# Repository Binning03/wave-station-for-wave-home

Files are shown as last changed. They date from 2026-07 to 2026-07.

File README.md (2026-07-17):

# WaveStation

> ESP32 기반 멀티모달 스마트홈 엣지 게이트웨이  
> 마이크·스피커·IR·환경 센서를 하나의 장치에 통합하고, 자체 설계한 **WSP(WaveStation Protocol)** 로 WaveHome 백엔드와 실시간 데이터를 주고받습니다.

WaveStation은 단순히 여러 센서를 ESP32에 연결한 장치가 아닙니다. 실시간 오디오 수집과 압축, 양방향 장치 제어, TCP 스트림 파싱, 구독 기반 데이터 전송, 오류 응답, 연결 복구까지 직접 설계한 **펌웨어·통신 미들웨어·테스트 백엔드 통합 프로젝트**입니다.

WaveHome 전체 시스템에서는 실제 공간의 데이터를 수집하고 제어 명령을 실행하는 디바이스 계층을 담당합니다. 이를 통해 **디바이스 → 엣지 펌웨어 → 네트워크 프로토콜 → 백엔드 → AI 서비스**로 이어지는 End-to-End 사용자 케어 시스템의 핵심 연결 지점을 구현했습니다.

---

## 핵심 구현 내용

| 영역 | 구현 내용 |
|---|---|
| Embedded Firmware | ESP32 기반 펌웨어, Wi-Fi 연결, 장치 초기화 및 세션 관리 |
| Audio Input/Output | INMP441 I2S 마이크 입력, MAX98357 I2S 스피커 출력 |
| Real-time Audio | 16 kHz·mono·16-bit PCM을 20 ms 프레임으로 실시간 스트리밍 |
| Audio Compression | ESP32 내부 Opus 인코딩·디코딩, 16 kbps 음성 스트림 전송 |
| Infrared | 리모컨 raw timing 수신 및 38 kHz 기반 IR 재송신 |
| Environment Sensors | DHT22 온도·습도, BH1750 조도 센서 연동 |
| Network | ESP32 TCP 서버, 부분 송신 재시도, TCP 스트림 누적 파싱 |
| WSP Protocol | 16-byte 바이너리 헤더, 데이터 타입, sequence, requestId 설계 |
| Control Messages | Subscribe, Unsubscribe, Heartbeat, Ack, Error 처리 |
| Error Handling | 미지원 기능, 잘못된 payload, 장치 준비 실패, 재생 실패 응답 |
| Execution Structure | 확장된 Arduino `loopTask` 안에서 기능별 비차단 폴링 루틴과 드라이버 모듈 분리 |
| Reliability | 스택 오버플로, 연결 종료·재연결, I2S 채널 문제, 라이브러리 충돌 디버깅 |
| Test Backend | 펌웨어와 함께 Python WSP 테스트 클라이언트 및 오디오 분석 도구 개발 |
| Enclosure | 센서 배치와 설치 환경을 고려한 OpenSCAD 케이스 및 STL 제작 |

### 이 프로젝트에서 특히 강조한 부분

- 단순 센서 연결보다 **직접 설계한 소프트웨어 구조와 문제 해결 과정**에 집중했습니다.
- 실시간 오디오가 프레임 단위로 끊기지 않도록 I2S 수집, 압축, TCP 송신 흐름을 연결했습니다.
- 제한된 ESP32 메모리와 스택을 고려해 큰 버퍼는 정적으로 관리하고 `loopTask` 스택을 **49,152 bytes**로 확장했습니다.
- TCP 위에서 사용할 바이너리 패킷의 헤더, 명령, 응답, 순서 번호 구조를 직접 정의했습니다.
- 장치가 지원하지 않거나 준비되지 않은 명령에는 `ErrorUnsupported` 등의 오류를 반환합니다.
- 연결이 종료되면 세션 상태와 sequence를 초기화하고 다음 백엔드 연결을 받을 수 있도록 구성했습니다.
- 실제 펌웨어와 동일한 프로토콜을 사용하는 Python 테스트 백엔드를 함께 만들어 기능을 독립적으로 검증했습니다.

---

## WaveHome에서의 역할

WaveHome은 수면 상태, 자세, 실내 환경 등을 종합적으로 관리하는 사용자 케어 스마트홈 시스템입니다. WaveStation은 그중 물리 환경과 서버를 연결하는 엣지 게이트웨이입니다.

```mermaid
flowchart LR
    subgraph Device["WaveStation Device"]
        MIC[INMP441 Microphone]
        IRRX[IR Receiver]
        IRTX[IR Transmitter]
        DHT[DHT22]
        LIGHT[BH1750]
        SPK[MAX98357 + Speaker]
        ESP[ESP32 Firmware]

        MIC --> ESP
        IRRX --> ESP
        DHT --> ESP
        LIGHT --> ESP
        ESP --> IRTX
        ESP --> SPK
    end

    ESP <-->|"TCP :41737 / WSP"| BACKEND[WaveHome Backend]
    BACKEND --> AI[Care Logic / AI Services]
    AI --> BACKEND
```

### 수집 방향

- 마이크 → PCM 또는 Opus → WaveHome 백엔드
- IR 수신기 → raw timing → WaveHome 백엔드
- BH1750 → 조도(lux) → WaveHome 백엔드
- DHT22 → 온도(°C)·습도(%) → WaveHome 백엔드

### 제어 방향

- WaveHome 백엔드 → IR raw timing → 기존 에어컨·가전 제어
- WaveHome 백엔드 → PCM 또는 Opus → 스피커 안내·알림 출력

이 저장소는 AI 분석 모델 자체보다 **디바이스 및 게이트웨이 계층**에 집중합니다. WaveHome 백엔드·AI 서비스와 결합하면 센서 입력부터 사용자 케어 동작까지 이어지는 End-to-End 시스템을 구성할 수 있습니다.

---

## 시스템 구성

```text
Sensors / Audio / IR
        ↓
ESP32 Hardware Drivers
        ↓
Feature Polling Routines
        ↓
WSP Packet Builder / Parser
        ↓
TCP Server :41737
        ↕
Python Test Backend or WaveHome Backend
```

### TCP 역할

| 구성 요소 | 역할 |
|---|---|
| ESP32 | TCP 서버, `41737` 포트에서 연결 대기 |
| Python/WaveHome 백엔드 | TCP 클라이언트, ESP32 LAN IP로 연결 |

ESP32는 한 번에 하나의 백엔드 연결을 처리합니다. 연결된 클라이언트에는 `TCP_NODELAY`를 적용해 작은 오디오 프레임의 지연을 줄입니다.

---

## 펌웨어 실행 구조

### 실제 실행 모델

ESP32 Arduino Core는 `setup()`과 `loop()`를 실행하는 FreeRTOS `loopTask`를 생성합니다. WaveStation은 Opus 인코더·디코더와 오디오 처리 과정에서 발생한 스택 오버플로를 해결하기 위해 해당 Task의 스택 크기를 **49,152 bytes**로 확장했습니다.

`appLoop()`에서는 다음 루틴을 짧게 반복합니다.

| 실행 루틴 | 책임 |
|---|---|
| TCP 수신 루틴 | 스트림 데이터 누적, WSP 패킷 경계 복원, 명령 dispatch |
| IR 수신 루틴 | 구독 상태일 때 리모컨 raw timing 확인 및 전송 |
| 센서 루틴 | 구독 주기와 변화량 조건을 확인해 환경 데이터 전송 |
| 마이크 루틴 | 20 ms PCM 프레임 수집, PCM/Opus 패킷 송신 |

기능별 로직은 다음 모듈로 분리되어 있습니다.

| 모듈 | 역할 |
|---|---|
| `app.cpp` | Wi-Fi, TCP 세션, 구독 상태, WSP 수신 dispatch, 기능 폴링 |
| `wave_station.h` | WSP 상수, 타입, 헤더와 payload 구조 정의 |
| `wsp_packet.*` | Ack/Error/Heartbeat 및 데이터 패킷 생성·송신 |
| `i2s_mic.*` | INMP441 I2S 입력과 PCM 변환 |
| `opus_codec.*` | MicComp 인코딩과 SpkComp 디코딩 |
| `ir_driver.*` | IR raw timing 수신·송신 |
| `sensor_driver.*` | DHT22·BH1750 초기화와 측정 |
| `speaker_driver.*` | MAX98357 I2S 출력 |

이 구조는 기능 책임을 분리하면서도, 별도 Task 간 Queue와 동기화 비용을 추가하지 않고 현재 규모의 기능을 하나의 실행 흐름에서 관리하도록 설계한 것입니다.

---

## WSP: WaveStation Protocol

WSP는 WaveStation과 백엔드가 오디오, IR, 센서, 제어 메시지를 동일한 형식으로 교환하기 위해 설계한 바이너리 프로토콜입니다.

### 기본 규격

| 항목 | 값 |
|---|---:|
| Protocol identifier | `0x57535031` |
| Version | `1` |
| Byte order | Little-endian |
| Header size | `16 bytes` |
| Maximum payload | `4,096 bytes` |
| TCP receive buffer | `8,192 bytes` |
| TCP port | `41737` |

모든 메시지는 고정 헤더와 가변 payload로 구성됩니다.

```text
16-byte Header | payloadSize bytes
```

### 헤더 분리

| 헤더 | 마지막 4-byte 필드 | 용도 |
|---|---|---|
| ControlHeader | `requestId` | Subscribe, Unsubscribe, Ack, Error, Heartbeat |
| DataHeader | `sequence` | PCM, Opus, IR, 센서 데이터 |

- `requestId`는 요청과 Ack/Error 응답을 연결합니다.
- `sequence`는 타입별 데이터 순서와 누락을 확인하는 데 사용합니다.
- 두 헤더는 모두 16 bytes이며 공통 앞부분을 사용합니다.

### 지원 메시지 타입

| Type | 값 | 방향 | 용도 |
|---|---:|---|---|
| MicPCM | `0x0101` | Device → Host | 원본 PCM 마이크 스트림 |
| MicComp | `0x0102` | Device → Host | Opus 압축 마이크 스트림 |
| SpkPCM | `0x0111` | Host → Device | PCM 스피커 재생 |
| SpkComp | `0x0112` | Host → Device | Opus 스피커 재생 |
| IrReceive | `0x0201` | Device → Host | IR raw timing 수신 결과 |
| IrTransmit | `0x0202` | Host → Device | IR raw timing 송신 명령 |
| AmbientLight | `0x0301` | Device → Host | 조도 |
| Temperature | `0x0302` | Device → Host | 온도 |
| Humidity | `0x0303` | Device → Host | 습도 |
| Subscribe | `0xF001` | Host → Device | 데이터 전송 시작 |
| Unsubscribe | `0xF002` | Host → Device | 데이터 전송 중지 |
| Ack | `0xF010` | Both | 요청 성공 응답 |
| Error | `0xF011` | Both | 요청 실패 응답 |
| Heartbeat | `0xF020` | Both | 연결 생존 확인 |

### Subscribe / Unsubscribe

백엔드는 필요한 데이터만 구독할 수 있습니다.

```mermaid
sequenceDiagram
    participant H as Backend
    participant D as WaveStation

    H->>D: Subscribe(Temperature, intervalMs)
    D->>H: Ack(requestId, status=0)
    loop Subscription enabled
        D->>H: Temperature(sequence, value)
    end
    H->>D: Unsubscribe(Temperature)
    D->>H: Ack(requestId, status=0)
```

구독 가능한 타입은 다음과 같습니다.

- MicPCM
- MicComp
- IrReceive
- AmbientLight
- Temperature
- Humidity

`SpkPCM`, `SpkComp`, `IrTransmit`은 구독 스트림이 아니라 백엔드가 필요할 때 보내는 일회성 Data 패킷입니다.

### Heartbeat

백엔드가 Heartbeat를 보내면 ESP32는 동일한 `requestId`로 Heartbeat를 반환합니다. Python 테스트 백엔드의 기본 주기는 **5초**이며 `0`으로 설정하면 비활성화할 수 있습니다.

### Ack와 Error

지원되는 Subscribe/Unsubscribe 요청이 정상 처리되면 `Ack(status=0)`를 반환합니다. 다음 상황에서는 Error 패킷을 반환합니다.

| 오류 코드 | 값 | 예시 |
|---|---:|---|
| ErrorUnsupported | `-1` | 미지원 타입, Opus/스피커/센서 준비 실패, 지원하지 않는 오디오 형식 |
| ErrorBusy | `-2` | 스피커 재생 실패 |
| ErrorInvalidPayload | `-3` | 잘못된 길이, 크기, sample count, IR raw 구조 |

오류 메시지는 최대 **96 bytes**까지 함께 전송합니다.

### TCP 스트림 파싱

TCP의 한 번의 `read()`는 WSP 패킷 하나와 일치하지 않을 수 있습니다. WaveStation은 수신 데이터를 **8 KB 버퍼**에 누적한 뒤 다음 조건을 확인합니다.

1. 16-byte 헤더가 모두 수신되었는지 확인
2. protocol identifier와 version 검증
3. payload가 4,096 bytes 이하인지 검증
4. 헤더와 payload 전체가 모일 때까지 대기
5. 완성된 패킷만 dispatch
6. 남은 바이트를 버퍼 앞으로 이동

잘못된 identifier/version, 과도한 payload, 수신 버퍼 overflow가 발생하면 연결을 종료해 파서 상태가 오염되는 것을 방지합니다.

### 송신 안정성

`WiFiClient.write()`가 전체 패킷을 한 번에 처리한다고 가정하지 않습니다. 실제 전송된 길이를 누적하며 남은 바이트를 계속 전송하고, 송신 버퍼가 잠시 가득 찬 경우 최대 **1초** 동안 재시도합니다.

---

## 실시간 오디오

### 마이크 입력

INMP441의 I2S 32-bit 슬롯에서 유효 샘플을 읽어 signed 16-bit PCM으로 변환합니다.

| 항목 | 값 |
|---|---:|
| Sample rate | `16,000 Hz` |
| Channels | `1 (mono)` |
| Bits per sample | `16-bit` |
| Frame duration | `20 ms` |
| Samples per frame | `320` |
| PCM bytes per frame | `640 bytes` |
| Frames per second | 약 `50` |
| Raw PCM bandwidth | 약 `32 KB/s` |
| WSP MicPCM packet size | `664 bytes` |

### I2S 슬롯 자동 선택

INMP441의 L/R 핀 설정과 ESP32 I2S 채널 해석이 맞지 않으면 한쪽 슬롯에서 거의 0인 값만 수집될 수 있습니다. 현재 드라이버는 left/right 슬롯을 모두 읽고 프레임별 절대 에너지를 비교해 실제 신호가 있는 슬롯을 자동 선택합니다.

이 처리는 다음과 같은 무음 문제를 해결하기 위해 추가했습니다.

- 녹음 파일은 생성되지만 대부분 0에 가까운 값
- 최댓값이 0이고 특정 음수 값만 반복
- `zero_ratio`가 0.99 이상으로 측정됨

### PCM 실시간 스트리밍

MicPCM을 구독하면 20 ms마다 320 samples를 수집해 WSP 패킷으로 전송합니다. `TCP_NODELAY`, 부분 송신 반복, 타입별 sequence를 적용해 작은 오디오 프레임을 연속적으로 처리합니다.

### Opus 압축

MicComp를 구독하면 동일한 PCM 프레임을 ESP32에서 Opus로 압축해 전송합니다.

| 항목 | 값 |
|---|---:|
| Codec | Opus |
| Application | VOIP |
| Target bitrate | `16 kbps` |
| Complexity | `0` |
| VBR | 비활성화 |
| Signal hint | Voice |
| Maximum encoded buffer | `512 bytes` |

연산량과 스택 사용량을 줄이기 위해 낮은 complexity를 사용합니다. Opus encoder가 초기화되지 않은 경우 MicComp 구독을 승인하지 않고 `ErrorUnsupported`를 반환합니다.

### 스피커 출력

백엔드는 PCM 또는 Opus 프레임을 WaveStation으로 보낼 수 있습니다.

- SpkPCM: 16 kHz·mono·16-bit PCM 재생
- SpkComp: Opus 디코딩 후 PCM 재생
- 최대 decoded frame: `960 samples`, 16 kHz 기준 `60 ms`
- mono 샘플을 I2S left/right 슬롯에 복제해 MAX98357 채널 설정에 따른 무음을 방지
- KeyFrame flag가 설정된 SpkComp 패킷에서는 Opus decoder 상태 초기화

---

## IR 송수신

### IR 수신

IRremoteESP8266 라이브러리를 사용해 리모컨 신호를 microsecond 단위 raw timing 배열로 수집합니다.

- 수신 핀: GPIO27
- 수신 및 전송 상한: 최대 `512` timing values
- timeout: `50 ms`
- 첫 leading gap을 제외하고 mark부터 전송
- 라이브러리 overflow 또는 길이 제한 발생 시 `overflow=1`
- 각 timing 값은 `uint16_t` 범위로 제한

IR 수신 드라이버, WSP 송신 버퍼, Python 테스트 백엔드의 허용 길이를 모두 512개 raw timing 기준으로 통일했습니다.

### IR 송신

백엔드가 보낸 raw timing을 IR LED로 재생합니다.

- 송신 핀: GPIO26
- 기본 carrier: `38,000 Hz`
- `repeat=0`은 1회, `repeat=N`은 총 `N+1`회 송신
- 반복 송신 사이 대기: `50 ms`

특정 제조사 프로토콜에 종속되지 않고 raw timing을 저장·재생하므로 기존 에어컨과 리모컨 기반 가전을 WaveHome에 연결할 수 있습니다.

---

## 온도·습도·조도 센서

| 데이터 | 센서 | 단위 | 기본/최소 전송 주기 |
|---|---|---|---:|
| AmbientLight | BH1750 | lux | 기본 1,000 ms / 최소 200 ms |
| Temperature | DHT22 | °C | 기본 2,000 ms / 최소 2,000 ms |
| Humidity | DHT22 | % | 기본 2,000 ms / 최소 2,000 ms |

### OnChangeOnly

Subscribe options의 OnChangeOnly flag를 사용하면 값이 충분히 변했을 때만 전송합니다.

| 데이터 | 변화 기준 |
|---|---:|
| 조도 | `1.0 lux` |
| 온도 | `0.2 °C` |
| 습도 | `1.0 %` |

정상 측정값은 `quality=255`, 읽기 실패는 `quality=0`과 값 `0`으로 전송합니다. 이를 통해 서버는 네트워크 연결 상태와 센서 측정 품질을 구분할 수 있습니다.

---

## 연결 종료와 재연결

WaveStation은 연결 상태를 다음과 같이 관리합니다.

1. Wi-Fi가 끊기면 다시 연결을 시도합니다.
2. 백엔드 연결이 없으면 TCP 서버에서 새 클라이언트를 확인합니다.
3. 새 연결이 수립되면 구독 상태, 수신 버퍼, sequence, 센서 변화 감지 상태를 초기화합니다.
4. 송신 실패, 잘못된 헤더, 과도한 payload, 수신 버퍼 overflow가 발생하면 현재 클라이언트를 종료합니다.
5. 이후 다음 백엔드 연결을 다시 받을 수 있습니다.

Python 테스트 백엔드는 서버가 연결을 종료하면 종료 코드와 함께 원인을 출력합니다. 운영 백엔드에서는 재접속 backoff 정책을 추가하는 것을 권장합니다.

---

## 하드웨어

### 사용 부품

| 부품 | 역할 | 인터페이스 |
|---|---|---|
| ESP32 Dev Board | 메인 MCU 및 Wi-Fi/TCP | Wi-Fi, GPIO, I2S, I2C |
| INMP441 | 디지털 마이크 | I2S RX |
| MAX98357 | I2S DAC/Amplifier | I2S TX |
| Speaker | 안내 음성·알림 출력 | MAX98357 |
| IR Receiver | 리모컨 신호 수신 | GPIO |
| IR Transmitter | 가전 제어 | GPIO |
| DHT22 | 온도·습도 | Digital GPIO |
| BH1750 | 조도 | I2C |

### 핀 배치

#### INMP441

| INMP441 | ESP32 |
|---|---|
| VDD | 3.3V |
| GND | GND |
| L/R | 3.3V or GND |
| SCK | GPIO14 |
| WS | GPIO15 |
| SD | GPIO32 |

#### IR

| 모듈 | ESP32 / 전원 |
|---|---|
| IR Receiver OUT | GPIO27 |
| IR Receiver VCC | 3.3V |
| IR Receiver GND | GND |
| IR Transmitter Signal | GPIO26 |
| IR Transmitter VCC | 5V |
| IR Transmitter GND | GND |

#### DHT22

| DHT22 | ESP32 |
|---|---|
| VCC | 3.3V |
| GND | GND |
| DATA | GPIO25 |

#### BH1750

| BH1750 | ESP32 |
|---|---|
| VCC | 3.3V |
| GND | GND |
| SDA | GPIO21 |
| SCL | GPIO22 |
| ADDR | GND |

#### MAX98357

| MAX98357 | ESP32 / 전원 |
|---|---|
| VIN | 5V |
| GND | GND |
| BCLK | GPIO18 |
| LRC | GPIO19 |
| DIN | GPIO23 |

모든 모듈의 GND는 공통으로 연결해야 합니다.

---

## 저장소 구조

```text
wavestation/
├─ README.md
├─ doc/
│  ├─ wave-station-protocol.md
│  └─ wave-station-esp32-guide.md
├─ esp32/
│  ├─ wave_station_firmware.ino
│  ├─ app.cpp
│  ├─ wave_station.h
│  ├─ wsp_packet.h / .cpp
│  ├─ i2s_mic.h / .cpp
│  ├─ opus_codec.h / .cpp
│  ├─ ir_driver.h / .cpp
│  ├─ sensor_driver.h / .cpp
│  ├─ speaker_driver.h / .cpp
│  └─ tools/send_spkpcm_tone.py
├─ test_backend/
│  ├─ wave_station_test_backend.py
│  ├─ check_raw.py
│  ├─ raw_to_wav.py
│  └─ test_scenarios.txt
└─ wavestation_case/
   ├─ wavestation_case.scad
   ├─ wavestation_case_base.stl
   └─ wavestation_case_lid.stl
```

---

## 개발 환경

### Arduino 설정

| 항목 | 설정 |
|---|---|
| Board | ESP32 Dev Module |
| Serial baud rate | 115200 |
| ESP32 Arduino Core | 2.0.17 |

### Arduino 라이브러리

Arduino Library Manager에서 다음 라이브러리를 설치합니다.

- IRremoteESP8266
- esp32_opus
- DHT sensor library
- Adafruit Unified Sensor
- BH1750

### Wi-Fi 설정

`esp32/app.cpp`의 Wi-Fi SSID와 비밀번호 placeholder를 개발 환경에 맞게 변경합니다.

---

## 실행 및 테스트

아래 예시는 ESP32 IP가 `192.168.0.50`이고, 현재 디렉터리가 `test_backend`인 경우입니다.

### 1. Heartbeat 및 기본 연결

```powershell
python wave_station_test_backend.py 192.168.0.50
```

### 2. MicPCM 녹음

```powershell
python wave_station_test_backend.py 192.168.0.50 `
  --subscribe micpcm `
  --pcm-out mic.raw `
  --heartbeat-interval 0
```

예상 raw PCM 크기:

| 녹음 시간 | 파일 크기 |
|---:|---:|
| 1초 | 약 32 KB |
| 3초 | 약 96 KB |
| 5초 | 약 160 KB |
| 10초 | 약 320 KB |

재생:

```powershell
ffplay -f s16le -ar 16000 -ac 1 mic.raw
```

### 3. PCM 통계 확인

```powershell
python check_raw.py
```

정상 음성은 일반적으로 음수와 양수 범위가 모두 나타나며, 말할 때 RMS가 증가합니다. `zero_ratio`가 0.99에 가깝고 최댓값이 0인 경우 I2S 슬롯이나 마이크 배선을 먼저 확인합니다.

### 4. raw를 WAV로 변환

```powershell
python raw_to_wav.py mic.raw mic.wav
```

### 5. MicComp Opus 프레임 저장

```powershell
python wave_station_test_backend.py 192.168.0.50 `
  --subscribe miccomp `
  --opus-out-dir opus_frames `
  --heartbeat-interval 0
```

20 ms 프레임이므로 정상 수신 시 약 50 frames/s가 생성됩니다. `.opusframe`은 정식 Ogg/Opus 파일이 아니라 WSP payload의 Opus encoded data만 저장한 디버그용 raw frame입니다.

### 6. IR 수신

```powershell
python wave_station_test_backend.py 192.168.0.50 `
  --subscribe ir `
  --ir-jsonl ir_raw.jsonl `
  --heartbeat-interval 0
```

`overflow=1`인 신호는 불완전할 수 있으므로 학습 데이터로 사용하지 않는 것이 안전합니다.

### 7. IR 송신

```powershell
python wave_station_test_backend.py 192.168.0.50 `
  --send-ir-raw "9000,4500,560,560,560,1690" `
  --carrier-hz 38000 `
  --repeat 0 `
  --heartbeat-interval 0
```

### 8. 환경 센서

```powershell
python wave_station_test_backend.py 192.168.0.50 `
  --subscribe ambient temperature humidity `
  --sensor-interval-ms 1000 `
  --heartbeat-interval 0
```

DHT22는 펌웨어에서 최소 2,000 ms로 보정되므로 명령에 1,000 ms를 지정해도 실제 온도·습도 전송 주기는 2,000 ms 이상입니다.

### 9. 스피커 사인파 테스트

```powershell
python wave_station_test_backend.py 192.168.0.50 `
  --send-spkpcm-tone `
  --tone-freq 880 `
  --tone-duration 2 `
  --tone-amp 0.15 `
  --heartbeat-interval 0
```

처음 테스트할 때는 낮은 진폭부터 사용합니다.

### 10. WAV 재생

권장 형식은 16 kHz, mono, signed 16-bit PCM입니다.

```powershell
ffmpeg -i input.wav -ar 16000 -ac 1 -sample_fmt s16 test_16k_mono.wav
python wave_station_test_backend.py 192.168.0.50 `
  --send-spkpcm-wav test_16k_mono.wav `
  --heartbeat-interval 0
```

### 11. 저장한 Opus 프레임 재생

```powershell
python wave_station_test_backend.py 192.168.0.50 `
  --send-spkcomp-dir opus_frames `
  --heartbeat-interval 0
```

테스트 백엔드는 Ctrl+C로 종료할 때 활성 구독에 대해 Unsubscribe를 전송합니다.

---

## 주요 문제 해결

### 1. I2S 마이크가 거의 무음으로 수집되는 문제

**증상**

- raw 파일 크기는 정상적으로 증가
- 값 대부분이 0
- 특정 음수 최솟값만 간헐적으로 발생

**원인**

INMP441의 L/R 설정과 ESP32가 읽는 I2S 슬롯이 일치하지 않아 빈 슬롯을 선택하고 있었습니다.

**해결**

- left/right 슬롯을 동시에 수집
- 각 슬롯의 프레임 에너지 계산
- 더 큰 신호가 존재하는 슬롯을 자동 선택
- L/R 배선도 함께 점검

### 2. Opus 사용 시 stack canary / 스택 오버플로

**원인**

Opus encoder·decoder 초기화와 프레임 처리 과정이 기본 Arduino `loopTask` 스택보다 많은 공간을 사용했습니다.

**해결**

- `loopTask` 스택을 49,152 bytes로 확장
- 큰 PCM·Opus 버퍼를 정적 영역에 배치
- Opus complexity를 0으로 설정
- 로그에 free heap을 출력해 런타임 상태 확인

### 3. TCP에서 패킷 경계가 보장되지 않는 문제

**원인**

TCP는 message 단위가 아닌 byte stream이므로 하나의 WSP 패킷이 여러 번 나뉘어 들어오거나 여러 패킷이 한 번에 수신될 수 있습니다.

**해결**

- 8 KB 수신 버퍼에 누적
- 16-byte 헤더와 payloadSize로 전체 길이 계산
- 완성된 패킷만 처리
- 남은 바이트 보존
- identifier/version/payloadSize 오류 시 연결 종료

### 4. 연결 종료 후 이전 구독 상태가 남는 문제

**해결**

새 백엔드가 연결될 때 다음 상태를 초기화합니다.

- Subscribe 상태
- TCP 수신 버퍼
- 타입별 sequence
- 센서 마지막 전송 시각
- OnChangeOnly 비교값

### 5. 미지원 장치와 잘못된 명령 처리

WSP Error 패킷으로 원인을 전달합니다.

- 준비되지 않은 Opus encoder/decoder
- 감지되지 않은 BH1750
- 초기화되지 않은 스피커
- 지원하지 않는 오디오 형식
- 잘못된 payload 길이
- 허용 범위를 벗어난 sample count 또는 IR 길이
- Subscribe 대상이 아닌 타입

---

## 3D 프린팅 케이스

WaveStation의 센서 노출, 음향 입출력, 전원 연결, 벽·헤드보드 설치를 고려해 전용 케이스를 OpenSCAD로 설계했습니다. 본체와 뚜껑은 각각 출력할 수 있으며, 조립 상태도 미리 확인할 수 있도록 모델의 출력 대상을 분리했습니다.

### 기본 치수

| 항목 | 값 |
|---|---:|
| 전체 외형 | 110 × 75 × 약 90 mm |
| 본체 높이 | 82 mm |
| 뚜껑 높이 | 8 mm |
| 벽 두께 | 2.4 mm |
| 바닥 두께 | 3 mm |
| 뚜껑 상판 두께 | 3.2 mm |
| X/Y 방향 전체 결합 여유 | 0.65 mm |
| 한쪽 기준 예상 간격 | 약 0.325 mm |
| 마찰 돌기 두께 | 0.30 mm |

### 센서 및 포트 개구부

모델 좌표는 정면을 `Y=0`, 후면을 `Y=75`, 왼쪽을 `X=0`, 오른쪽을 `X=110`으로 정의했습니다.

| 면 | 대상 | 크기 및 형태 | 중심 위치 또는 범위 |
|---|---|---|---|
| 정면 | I2S 마이크 | Ø15 mm 원형 | X=24, Z=23 mm |
| 정면 | IR 수신부 | 6 × 8 mm 라운드 사각형 | X=55, Z=37 mm |
| 정면 | 스피커 | 23 × 14 mm 캡슐형 | X=84, Z=23 mm |
| 상단 | IR 송신 LED | Ø7.2 mm 원형 | X=25, Y=22 mm |
| 상단 | BH1750 조도 센서 | 5.5 × 3.5 mm 라운드 사각형 | X=82, Y=23 mm |
| 왼쪽 | USB-C 전원 포트 | 17 × 11 mm 라운드 슬롯 | 후면에서 23.5\~40.5 mm, 바닥에서 12\~23 mm |
| 오른쪽 | 온·습도 센서 | 21 × 16 mm 직사각형 | 중심 Y=54, Z=30 mm |
| 후면 | 벽·헤드보드 고정부 | 2개의 keyhole | X=32·78 mm, 약 Z=31~49 mm |

정면 상단에는 `Wave Station` 텍스트를 양각으로 배치하고, 뚜껑에는 외부 SVG 없이 OpenSCAD 형상만으로 구성한 WaveStation 로고를 양각으로 적용했습니다.

### 뚜껑 결합 구조

뚜껑은 나사나 별도 체결 부품 없이 내부 skirt와 네 면의 마찰 돌기를 이용해 고정하는 friction-fit 구조입니다. `0.65 mm`는 한쪽 여유가 아니라 X축과 Y축 각각의 **전체 결합 여유**이며, 이론상 한쪽 간격은 약 `0.325 mm`입니다. 전·후·좌·우에는 `0.30 mm` 두께의 마찰 돌기를 배치해 흔들림을 줄였습니다.

OpenSCAD의 출력 선택값을 이용해 다음 형태로 렌더링하거나 STL로 내보낼 수 있습니다.

- `assembly`: 본체와 뚜껑의 조립 배치 확인
- `base`: 본체만 출력
- `lid`: 뚜껑만 출력

---

## WaveStation 요약

- ESP32 기반 멀티센서·멀티미디어 펌웨어 개발
- I2S DMA 기반 실시간 마이크 입력 및 스피커 출력
- PCM 프레임 처리와 Opus 압축·복원
- TCP 스트림 기반 바이너리 프로토콜 설계와 구현
- Subscribe/Unsubscribe/Heartbeat/Ack/Error 제어 흐름 설계
- 제한된 임베디드 메모리와 Task 스택을 고려한 버퍼 구조 설계
- 미지원 장치와 잘못된 요청에 대한 명시적 오류 처리
- 연결 종료·재연결 시 세션 상태 복구
- Python 테스트 백엔드와 분석 도구를 활용한 통합 검증
- 하드웨어 배치와 사용 환경을 고려한 3D 케이스 제작

**WaveStation은 디바이스부터 네트워크, 백엔드 테스트 환경까지 직접 구현하고, WaveHome AI 서비스로 연결되는 End-to-End 시스템의 핵심 게이트웨이를 설계한 프로젝트입니다.**

---

## 상세 문서

- `doc/wave-station-protocol.md`: WSP 패킷 필드와 타입 상세 명세
- `doc/wave-station-esp32-guide.md`: ESP32 구현 과정과 설계 참고 문서

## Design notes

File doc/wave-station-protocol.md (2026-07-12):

# WaveStation Binary Protocol (WSP1)

WaveStation(ESP32 DevKitC v4)과 C++ 백엔드 간 바이너리 통신 프로토콜 명세입니다.

- **Magic**: `WSP1` (`0x57535031`)
- **Protocol version**: `1`
- **Byte order**: Little-endian
- **Namespace**: `wsp`
- **TCP port**: `41737` (`wsp::kTcpPort`)
- **TCP 역할**: **ESP32 = 서버(listen)**, **백엔드(호스트) = 클라이언트(connect)**

---

## 1. 개요

WaveStation은 마이크(INMP441), 스피커(예정), IR, 조도/온도/습도 센서(예정)를 ESP32에 연결한 엣지 디바이스입니다. 본 프로토콜은 장치와 호스트(PC/서버) 간 **오디오 스트림**, **IR raw 타이밍**, **센서 값**, **구독 제어**를 단일 바이너리 포맷으로 주고받기 위한 것입니다.

### 1.1 Transport — TCP 41737

WaveStation ESP32는 공유기(WiFi)에 연결된 뒤 **TCP 41737 포트에서 listen** 합니다. 백엔드(wave-server)가 장치의 LAN IP로 **connect** 합니다.

```
[백엔드 :8500]  ──TCP connect──▶  [ESP32 :41737 listen]
         ◀──── WSP1 패킷 ────▶
```

| 항목 | 값 |
|---|-----|
| 포트 | **41737** |
| ESP32 역할 | TCP **서버** (`0.0.0.0:41737` bind + accept) |
| 백엔드 역할 | TCP **클라이언트** |
| 장치 주소 | 공유기 DHCP IP (고정 IP·DHCP 예약 권장) |
| 재접속 | 연결 끊김 시 **백엔드**가 재 connect (지수 백오프) |

각 패킷은 다음 형태입니다.

```
+--------+------------------+
| Header | Payload (Body)   |
| 16 B   | payloadSize bytes|
+--------+------------------+
```

- `payloadSize`는 **0 ~ kMaxPayload(4096)** 범위를 권장합니다.
- 한 TCP 메시지 = 한 WSP1 패킷으로 매핑합니다.

---

## 2. 공통 헤더

제어 메시지와 데이터 메시지 모두 **16바이트 고정 헤더**를 사용합니다.

### 2.1 ControlHeader (Subscribe, Unsubscribe, Ack, Error, Heartbeat)

| Offset | Size | Field | Description |
| --- | ---- | --- | --- |
| 0 | 4 | magic | `0x57535031` ("WSP1") |
| 4 | 1 | version | `1` |
| 5 | 1 | reserved | `0` |
| 6 | 2 | type | [Type](#3-message-types) |
| 8 | 4 | payloadSize | Body 길이 (바이트) |
| 12 | 4 | requestId | Ack/Error 매칭용 요청 ID |

### 2.2 DataHeader (오디오, IR, 센서)

| Offset | Size | Field | Description |
| --- | ---- | --- | --- |
| 0 | 4 | magic | `0x57535031` ("WSP1") |
| 4 | 1 | version | `1` |
| 5 | 1 | flags | [HeaderFlagBits](#31-header-flags) |
| 6 | 2 | type | [Type](#3-message-types) |
| 8 | 4 | payloadSize | Payload 전체 길이 (바이트) |
| 12 | 4 | sequence | 타입별 순번 (손실/순서 검출) |

### 3.1 Header flags

| Bit | Name | Description |
| --- | --- | --- |
| 0 | HeaderFlag_HasTimestampBit | Payload 앞에 `TimestampPrefix` 포함 |
| 1 | HeaderFlag_LastFrameBit | 오디오/스트림 종료 프레임 |
| 2 | HeaderFlag_KeyFrameBit | 압축 오디오 디코더 리셋/동기용 키프레임 |

---

## 3. Message types

| Value  | Name | Direction | Header | Body |
| --- | --- | --- | --- | --- |
| 0x0101 | MicPCM | device → host | DataHeader | AudioPCMBody + PCM |
| 0x0102 | MicComp | device → host | DataHeader | AudioCompBody + Opus |
| 0x0111 | SpkPCM | host → device | DataHeader | AudioPCMBody + PCM |
| 0x0112 | SpkComp | host → device | DataHeader | AudioCompBody + Opus |
| 0x0201 | IrReceive | device → host | DataHeader | IrReceiveBody + raw  |
| 0x0202 | IrTransmit | host → device | DataHeader | IrTransmitBody + raw |
| 0x0301 | AmbientLight | device → host | DataHeader | SensorBody |
| 0x0302 | Temperature  | device → host | DataHeader | SensorBody |
| 0x0303 | Humidity | device → host | DataHeader | SensorBody |
| 0xF001 | Subscribe | host → device | ControlHeader | SubscribeBody |
| 0xF002 | Unsubscribe  | host → device | ControlHeader | UnsubscribeBody |
| 0xF010 | Ack | either | ControlHeader | AckBody |
| 0xF011 | Error | either | ControlHeader | ErrorBody + msg |
| 0xF020 | Heartbeat | either | ControlHeader | (empty) |

---

## 4. Payload 레이아웃 (DataHeader)

DataHeader 패킷의 Payload는 아래 순서로 구성됩니다.

```
[TimestampPrefix]   optional (flags & HasTimestamp)
[TypeBody]          fixed struct per type
[VariableData]      trailing bytes
```

**payloadSize = TimestampPrefix(optional) + TypeBody + VariableData**

### TimestampPrefix (8 bytes, optional)

| Field | Type | Description |
| --- | --- | --- |
| timestampUs | uint64_t | 장치 부팅 후 경과 μs |

---

## 5. 제어 평면

### 5.1 Subscribe

호스트가 특정 데이터 타입의 스트리밍/주기 전송을 요청합니다.

**SubscribeBody (8 bytes)**

| Field | Type | Description |
| --- | --- | --- |
| targetType | uint16_t | 구독할 Type (MicComp, AmbientLight 등) |
| intervalMs | uint16_t | 센서: 전송 주기(ms). 오디오: `0` = 최대 속도 |
| options | uint32_t | SubscribeOptionFlagBits |

**SubscribeOptionFlagBits**

| Bit | Name | Description |
| --- | --- | --- |
| 0 | SubscribeOptionFlag_OnChangeOnlyBits | 센서: 값 변경 시에만 전송 |
| 1 | SubscribeOptionFlag_CompressedBits | 오디오: MicComp/SpkComp 선호 |

**흐름 예시**

```
Host  -> Device : Subscribe(MicComp, intervalMs=0, Compressed)
Device -> Host  : Ack(requestId, status=0)
Device -> Host  : DataHeader(MicComp, seq=0) + AudioCompBody + opus...
Device -> Host  : DataHeader(MicComp, seq=1) + ...
```

### 5.2 Unsubscribe

**UnsubscribeBody (2 bytes)**

| Field | Type | Description |
| --- | --- | --- |
| targetType | uint16_t | 해제할 Type |

`payloadSize = 2`

### 5.3 Ack

**AckBody (8 bytes)**

| Field | Type | Description |
| --- | --- | --- |
| requestId | uint32_t | 원 요청 ID |
| status | uint8_t | `0` = 성공 |
| reserved  | uint8_t[3] | `0` |

### 5.4 Error

**ErrorBody (8 bytes + optional message)**

| Field | Type | Description |
| --- | --- | --- |
| requestId | uint32_t | 원 요청 ID |
| code | int32_t  | ErrorCode |

**ErrorCode**

| Value | Name | Description |
| ----- | --- | --- |
| 0 | ErrorOk | 성공 |
| -1 | ErrorUnsupported | 미지원 타입/코덱 |
| -2 | ErrorBusy | 장치 사용 중 |
| -3 | ErrorInvalidPayload | 잘못된 payload |

가변 메시지 길이:

```
messageLen = payloadSize - 8
```

메시지는 ErrorBody 직후 ASCII/UTF-8 바이트열로 이어집니다. null terminator는 사용하지 않습니다.

### 5.5 Heartbeat

- `ControlHeader.type = Heartbeat`
- `payloadSize = 0` (Body 없음)
- 연결 유지 및 장치 alive 확인용

---

## 6. 오디오

### 6.1 기본 파라미터 (권장)

| 항목 | 값 |
| --- | --- |
| Sample rate | 16000 Hz |
| Channels | 1 (mono) |
| PCM bit depth | 16-bit signed |
| PCM frame | 320 samples / 20 ms |
| Compression | Opus, 20 ms frame |
| Opus bitrate  | 24–32 kbps (협의) |

### 6.2 AudioPCMBody (MicPCM, SpkPCM)

| Field | Type | Description |
| --- | --- | --- |
| sampleRate | uint32_t  | Hz |
| channels | uint8_t | 1 = mono |
| bitsPerSample | uint8_t | 16 |
| sampleCount | uint16_t  | 채널당 샘플 수 |
| pcmData | uint8_t[] | trailing PCM bytes |

**PCM 데이터 크기**

```
pcmBytes = sampleCount * channels * (bitsPerSample / 8)
payloadSize = sizeof(TimestampPrefix?) + 8 + pcmBytes
```

20 ms @ 16 kHz mono 16-bit 예: `sampleCount=320`, `pcmBytes=640`

### 6.3 AudioCompBody (MicComp, SpkComp)

| Field | Type | Description |
| --- | --- | --- |
| codec | uint8_t | `1` = Opus |
| sampleRate | uint32_t  | Hz |
| channels | uint8_t | 1 = mono |
| frameDurationMs | uint8_t | 20, 40, 60 ... |
| encodedSize | uint16_t  | 인코딩 데이터 길이 |
| encodedData | uint8_t[] | Opus 프레임 |

```
payloadSize = sizeof(TimestampPrefix?) + 9 + encodedSize
```

**SpkComp (PC → 장치)**: 호스트가 Opus로 인코딩한 프레임을 전송하면, ESP32에서 Opus 디코더로 PCM 변환 후 I2S 스피커 출력이 가능합니다. MicComp와 동일 코덱/파라미터를 사용합니다.

**KeyFrame**: `HeaderFlag_KeyFrameBit`가 설정된 프레임은 디코더 상태를 리셋하거나 동기화할 때 사용합니다.

---

## 7. IR

IRremoteESP8266 라이브러리의 raw 타이밍을 **마이크로초(μs)** 단위 `uint16_t` 배열로 주고받습니다. 배열은 **mark/space가 교대**하며, **첫 값은 mark**입니다. WaveStation 구현에서 `length`의 허용 범위는 **1~512개**입니다.

### 7.1 IrReceive (device → host)

**IrReceiveBody (4 bytes + raw)**

| Field | Type | Description |
| --- | --- | --- |
| length | uint16_t | mark/space 개수 |
| overflow | uint8_t | `1` = raw 버퍼 overflow 발생 |
| reserved | uint8_t | `0` |
| rawData  | uint16_t[] | μs 단위 타이밍 |

```
rawBytes = length * 2
payloadSize = sizeof(TimestampPrefix?) + 4 + rawBytes
```

### 7.2 IrTransmit (host → device)

**IrTransmitBody (8 bytes + raw)**

| Field | Type | Description |
| --- | --- | --- |
| length | uint16_t | mark/space 개수 |
| carrierHz | uint32_t | 반송파 주파수 (기본 38000) |
| repeat | uint16_t | `0` = 1회, `N` = (N+1)회 |
| rawData | uint16_t[] | μs 단위 타이밍 |

장치는 `rawData`를 IR LED로 송신합니다 (예: `IRsend::sendRaw`).

---

## 8. 센서

AmbientLight, Temperature, Humidity 모두 **SensorBody (8 bytes)** 를 사용합니다.

| Field | Type | Description |
| --- | --- | --- |
| unit | uint8_t  | SensorUnit |
| quality  | uint8_t  | `0`=invalid, `255`=good |
| reserved | uint16_t | `0` |
| value | float | IEEE 754 little-endian  |

**SensorUnit**

| Value | Name | Type | Unit |
| ----- | --- | --- | --- |
| 1 | UnitLux | AmbientLight | lux |
| 2 | UnitCelsius | Temperature  | °C |
| 3 | UnitPercent | Humidity | % (0–100) |

센서는 Subscribe 후 `intervalMs` 주기(또는 OnChangeOnly)로 DataHeader + SensorBody를 전송합니다.

---

## 9. Hex 예시

### 9.1 Subscribe (MicComp)

```
ControlHeader:
  magic       31 50 53 57   ("WSP1")
  version     01
  reserved    00
  type        01 F0         (Subscribe = 0xF001)
  payloadSize 08 00 00 00   (8)
  requestId   01 00 00 00   (1)

SubscribeBody:
  targetType  02 01         (MicComp)
  intervalMs  00 00
  options     02 00 00 00   (Compressed)
```

### 9.2 MicComp data frame (Opus, no timestamp)

```
DataHeader:
  magic       31 50 53 57
  version     01
  flags       00
  type        02 01         (MicComp)
  payloadSize XX 00 00 00   (9 + encodedSize)
  sequence    00 00 00 00

AudioCompBody (9 bytes fixed):
  codec           01        (Opus)
  sampleRate      80 3E 00 00  (16000)
  channels        01
  frameDurationMs 14        (20)
  encodedSize     XX XX

encodedData: [encodedSize bytes]
```

### 9.3 IrReceive (4 marks/spaces = length 4)

```
IrReceiveBody:
  length     04 00
  overflow   00
  reserved   00
  rawData    90 00 E0 01 90 00 ...  (900us mark, 480us space, ...)
```

---

## 10. Payload size helpers

헤더 파일에 고정 body 크기 상수와 가변 tail 계산 헬퍼가 포함되어 있습니다.

| Symbol | Description |
| --- | --- |
| `kTimestampPrefixSize` | 8 |
| `kSubscribeBodySize` | 8 |
| `kUnsubscribeBodySize` | 2 |
| `kAckBodySize` | 8 |
| `kErrorBodyFixedSize` | 8 |
| `kAudioPCMBodySize` | 8 |
| `kAudioCompBodySize` | 9 |
| `kIrReceiveBodySize` | 4 |
| `kIrTransmitBodySize` | 8 |
| `kSensorBodySize` | 8 |
| `pcm_data_size(body)` | PCM trailing byte length |
| `ir_raw_data_size(length)` | IR raw array byte length |
| `error_msg_size(payloadSize)` | Error optional message length |

---

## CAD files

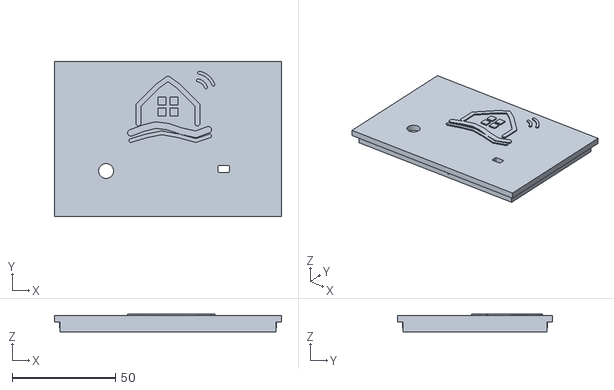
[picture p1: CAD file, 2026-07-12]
wavestation_case/wavestation_case_lid.stl
110.0 x 75.0 x 8.65

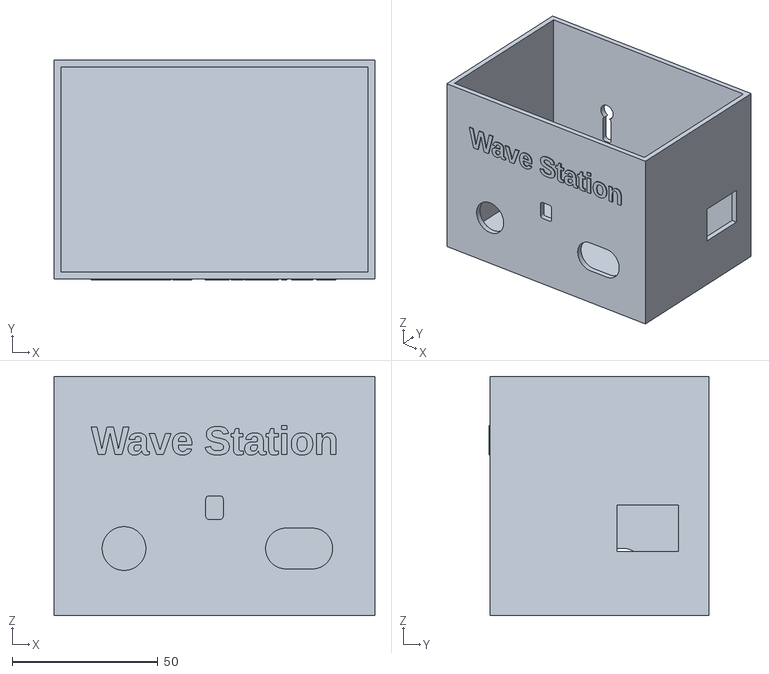
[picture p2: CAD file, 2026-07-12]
wavestation_case/wavestation_case_base.stl
110.0 x 75.4 x 82.0

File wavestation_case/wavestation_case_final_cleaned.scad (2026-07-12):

// WaveStation OpenSCAD final model
// Size: 110 x 75 x 90 mm approx.
// Lid fit: 0.65 mm total clearance in X/Y, 0.30 mm friction bumps on all sides.
// Units: mm
// Orientation: X left-right, Y front-back, Z vertical
// Front Y=0 faces bed/room, Back Y=D faces wall/headboard
// X=0 is left/corner, X=W is right/window/desk

$fn = 64;

W = 110;
D = 75;
BASE_H = 82;
LID_H = 8;
WALL = 2.4;
BOTTOM = 3;
LID_TOP = 3.2;

// Lid fit tuning
// CLEAR_X/Y are total clearances, not per-side clearances.
// With 0.65 mm total clearance, each side has about 0.325 mm gap.
// Friction bumps are 0.30 mm thick on all four sides.
CLEAR_X = 0.65;
CLEAR_Y = 0.65;

// ===== 2D helpers =====
module slot2d(w,h,r=1.2) {
    offset(r=r) offset(delta=-r) square([w,h], center=true);
}

// Capsule: rectangle with semicircles on left/right sides.
// w = total width, h = total height. Must satisfy w >= h.
module capsule2d(w,h) {
    hull() {
        translate([-w/2 + h/2, 0]) circle(d=h);
        translate([ w/2 - h/2, 0]) circle(d=h);
    }
}

// ===== Front wall cutters, Y=0 =====
module cut_front_slot(x,z,w,h,r=1.5) {
    translate([x, -1, z]) rotate([-90,0,0])
        linear_extrude(height=WALL+3)
            slot2d(w,h,r);
}

module cut_front_circle(x,z,d) {
    translate([x, -1, z]) rotate([-90,0,0])
        cylinder(h=WALL+3, d=d);
}

module cut_front_capsule(x,z,w,h) {
    translate([x, -1, z]) rotate([-90,0,0])
        linear_extrude(height=WALL+3)
            capsule2d(w,h);
}

// ===== Side wall cutters =====
// Left side X=0. len_y = front-back length, height_z = vertical height.
module cut_left_slot(y,z,len_y,height_z,r=1.5) {
    translate([-1,0,0])
        hull() {
            translate([0, y-len_y/2+height_z/2, z]) rotate([0,90,0]) cylinder(h=WALL+4, d=height_z);
            translate([0, y+len_y/2-height_z/2, z]) rotate([0,90,0]) cylinder(h=WALL+4, d=height_z);
        }
}

// Right side X=W. len_y = front-back length, height_z = vertical height.
module cut_right_slot(y,z,len_y,height_z,r=1.5) {
    translate([W-WALL-1,0,0])
        hull() {
            translate([0, y-len_y/2+height_z/2, z]) rotate([0,90,0]) cylinder(h=WALL+5, d=height_z);
            translate([0, y+len_y/2-height_z/2, z]) rotate([0,90,0]) cylinder(h=WALL+5, d=height_z);
        }
}

// Right side rectangular window cutter: sharp rectangular opening on Y-Z plane.
// len_y = front-back horizontal length, height_z = vertical height.
module cut_right_rect(y,z,len_y,height_z) {
    translate([W-WALL-1, y-len_y/2, z-height_z/2])
        cube([WALL+5, len_y, height_z]);
}

// ===== Top/lid cutters =====
module cut_top_circle(x,y,d) {
    translate([x,y,LID_H-LID_TOP-1])
        cylinder(h=LID_TOP+3, d=d);
}

module cut_top_slot(x,y,w,h,r=1.0) {
    translate([x,y,LID_H-LID_TOP-1])
        linear_extrude(height=LID_TOP+3)
            slot2d(w,h,r);
}


// ===== Logo / front decoration helpers =====
module line2d(p1, p2, w=2) {
    hull() {
        translate(p1) circle(d=w);
        translate(p2) circle(d=w);
    }
}

module polyline2d(points, w=2) {
    for (i=[0:len(points)-2]) line2d(points[i], points[i+1], w);
}

module arc2d(cx, cy, r, a1, a2, w=2, steps=12) {
    pts = [for (i=[0:steps]) [cx + r*cos(a1 + (a2-a1)*i/steps), cy + r*sin(a1 + (a2-a1)*i/steps)]];
    polyline2d(pts, w);
}

// Simplified WaveStation logo modeled directly in OpenSCAD.
// No external SVG file is required.
module wavestation_logo_2d() {
    union() {
        // house outline
        polyline2d([[-19,-4],[-19,8],[-7,20],[0,25],[7,20],[19,8],[19,-4]], 3.2);

        // 2x2 window
        for (xx=[-3.8,3.8]) for (yy=[3.5,10.5])
            translate([xx,yy]) square([5,5], center=true);

        // wave stroke under the house
        polyline2d([[-24,-10],[-16,-7],[-8,-5],[0,-6],[9,-9],[18,-11],[26,-8]], 4.2);
        polyline2d([[-24,-15],[-14,-12],[-4,-10],[7,-12],[18,-15],[27,-12]], 2.4);

        // wireless signal arcs
        arc2d(18,17,7,20,80,1.9,10);
        arc2d(18,17,12,20,80,1.9,10);
    }
}

module base() {
    difference() {
        union() {
            // Flat bottom + four walls, open top.
            cube([W,D,BOTTOM]);
            cube([W,WALL,BASE_H]);
            translate([0,D-WALL,0]) cube([W,WALL,BASE_H]);
            cube([WALL,D,BASE_H]);
            translate([W-WALL,0,0]) cube([WALL,D,BASE_H]);

            // Raised text on the upper front face.
            translate([W/2, 0.18, 60])
                rotate([90,0,0])
                    linear_extrude(height=0.55)
                        text("Wave Station", size=10, halign="center", valign="center", font="Liberation Sans:style=Bold");
        }

        // LEFT: ESP32 USB-C power opening.
        // Range from back face: 23.5~40.5 mm.
        // Range from bottom:    12~23 mm.
        USB_Y = D - 32;
        USB_Z = 17.5;
        USB_LEN = 17;
        USB_H = 11;
        cut_left_slot(USB_Y, USB_Z, USB_LEN, USB_H, 1.6);

        // RIGHT: temperature/humidity sensor opening.
        // Plain rectangular window, not rounded/capsule.
        DHT_Y = D - 21;
        DHT_Z = 30;      // aligned with front speaker center height
        DHT_WIN_LEN = 21;
        DHT_WIN_H = 16;
        cut_right_rect(DHT_Y, DHT_Z, DHT_WIN_LEN, DHT_WIN_H);

        // FRONT LEFT: microphone opening, 15 mm round.
        cut_front_circle(24, 23, 15);

        // FRONT CENTER: IR receiver visible part only, 6 x 8 mm.
        cut_front_slot(W/2, 37, 6, 8, 1.0);

        // FRONT RIGHT: speaker opening, capsule shape 23 x 14 mm.
        // Shape = rectangle with semicircles on both left/right sides.
        cut_front_capsule(84, 23, 23, 14);

        // BACK: wall/headboard keyholes.
        // BASE_H = 82 mm, keyhole range is roughly Z 31~49 mm.
        KEY_CIRCLE_Z = 46;
        KEY_SLOT_Z = 37;
        for (xx=[32,78]) {
            translate([xx,D-WALL-1,KEY_CIRCLE_Z]) rotate([-90,0,0])
                cylinder(h=WALL+3,d=6.8);
            translate([xx,D-WALL-1,KEY_SLOT_Z]) rotate([-90,0,0])
                linear_extrude(height=WALL+3)
                    slot2d(4.6,12,1.3);
        }
    }
}

module lid() {
    skirtW = W - 2*WALL - CLEAR_X;
    skirtD = D - 2*WALL - CLEAR_Y;
    skirtT = 1.4;
    skirtH = LID_H - 0.6;
    sx = (W-skirtW)/2;
    sy = (D-skirtD)/2;

    difference() {
        union() {
            // Top plate
            translate([0,0,LID_H-LID_TOP]) cube([W,D,LID_TOP]);

            // Raised top logo.
            // Approximate bounds after scaling: X 35~78 mm, Y 36~70 mm.
            // Orientation: upright/readable when facing the front side Y=0.
            translate([W/2, 48, LID_H + 0.05])
                linear_extrude(height=0.6)
                    scale([0.75, 0.75, 1])
                        wavestation_logo_2d();

            // Friction-fit internal skirt
            translate([sx,sy,0]) cube([skirtW,skirtT,skirtH]);
            translate([sx,sy+skirtD-skirtT,0]) cube([skirtW,skirtT,skirtH]);
            translate([sx,sy,0]) cube([skirtT,skirtD,skirtH]);
            translate([sx+skirtW-skirtT,sy,0]) cube([skirtT,skirtD,skirtH]);

            // Friction bumps, 0.30 mm on front/back/left/right.
            translate([W/2-9, sy-0.30, 2]) cube([18,0.30,2.7]);
            translate([W/2-9, sy+skirtD, 2]) cube([18,0.30,2.7]);

            translate([sx-0.30, D/2-8, 2]) cube([0.30,16,2.5]);
            translate([sx+skirtW, D/2-8, 2]) cube([0.30,16,2.5]);
        }

        // TOP LEFT: IR transmitter LED only, 7.2 mm circular hole.
        cut_top_circle(25, 22, 7.2);

        // TOP RIGHT: BH1750 light sensor visible part only, 5.5 x 3.5 mm.
        cut_top_slot(82, 23, 5.5, 3.5, 0.7);
    }
}

// ===== Display/export selector =====
// "assembly" : preview base + lid together
// "base"     : export base only
// "lid"      : export lid only
PART = "assembly";

if (PART == "base") {
    base();
} else if (PART == "lid") {
    lid();
} else {
    base();
    translate([0,0,BASE_H+12]) lid();
}

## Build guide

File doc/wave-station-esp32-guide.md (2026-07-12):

# WaveStation ESP32 구현 가이드

이 문서는 **무엇을 어떤 순서로 만들면 되는지**, **PC와 어떻게 대화하는지**, **ESP32 안에서 데이터가 어떻게 흐르는지**에 집중합니다.

---

## 0. 한 줄 요약

```
ESP32 = 공유기 WiFi 연결 → TCP 41737에서 서버(listen)
      → 백엔드가 접속하면 16바이트 헤더 + Body 패킷 주고받기
      → Subscribe 받으면 마이크/IR/센서 데이터를 보냄
      → 백엔드가 보낸 스피커/IR 명령을 실행
```

ESP32가 **서버**, PC가 **클라이언트**입니다. ESP32는 **41737** 포트에서 listen 하고, PC가 ESP32의 해당 포트에 접속합니다.

---

## 1. 먼저 이해해야 하는거

### 1.1 패킷 = 헤더 16바이트 + 내용

모든 메시지는 같은 모양입니다.

```
┌────────────────┬──────────────────────────────┐
│ Header (16 B)  │ Payload (payloadSize bytes)  │
└────────────────┴──────────────────────────────┘
```

헤더 종류는 두 가지뿐입니다.

| 헤더 | 쓰는 경우  | 예시 |
| --- | --- | --- |
| ControlHeader | 명령·응답  | Subscribe, Ack, Heartbeat  |
| DataHeader | 실제 데이터 | MicComp, IrReceive, Sensor |

**TCP 1회 send = WSP1 패킷 1개**로 맞추면 파싱이 쉽습니다.

### 1.2 두 가지 통신 방식

| 방식 | 흐름 | 의미 |
| --- | --- | --- |
| 제어 (Control) | PC ---> ESP32 | "마이크 보내줘" (Subscribe) |
| 데이터 (Data) | ESP32 <--> C (스피커는 반대) | 실제 오디오·IR·센서 바이트 |

데이터를 보내기 전에, 백엔드가 **Subscribe**로 먼저 요청합니다. ESP32는 **Ack**로 "알겠다"고 답한 뒤 스트리밍을 시작합니다.

### 1.3 구현 우선순위 (추천)

한 번에 다 만들지 말고 단계를 나눕니다. 참고로 Heartbeat는 장치가 살아있는지 확인하는 패킷입니다.

| 단계  | 목표 | 확인 방법 |
| --- | --- | --- |
| 1 | WiFi + TCP listen + accept + Heartbeat | 백엔드에서 connect 후 Heartbeat 확인 |
| 2 | Subscribe / Ack | 백엔드가 MicComp 구독 → Ack 확인 |
| 3 | 마이크 PCM 전송 (MicPCM) | 백엔드에서 소리 파형 확인 |
| 4 | 마이크 Opus (MicComp) | 대역 절약 스트림 |
| 5 | IR 수신 (IrReceive) | 리모컨 누르면 백엔드에 패킷 도착 |
| 6 | IR 송신 (IrTransmit) | 백엔드 명령으로 TV 켜기 |
| 7 | 스피커 (SpkComp) | 백엔드에서 TTS 재생 |
| 8 | 센서 | 주기적으로 값 전송 |

---

## 2. 전체 구조 (백엔드 ↔ ESP32)

```mermaid
flowchart LR
    subgraph Backend["백엔드 / wave-server :8500"]
        Client["TCP 클라이언트"]
        Parser["WSP1 파서"]
        Agent["에이전트 / 홈케어 로직"]
        Client --> Parser --> Agent
    end

    subgraph ESP32["ESP32 DevKitC v4 (공유기 WiFi)"]
        WiFi["WiFi 스택"]
        Srv["TCP 서버 :41737"]
        RX["수신 파이프라인"]
        TX["송신 파이프라인"]
        HW["하드웨어 드라이버"]

        WiFi --> Srv
        Srv --> RX
        TX --> Srv
        RX --> HW
        HW --> TX
    end

    Client <-->|"WSP1 패킷"| Srv
```

역할 정리:

- **ESP32**: 공유기 WiFi 연결 → `0.0.0.0:41737` listen → 백엔드 접속 대기 → 명령 처리·데이터 송신.
- **백엔드**: `device_list` 등에 등록된 ESP32 LAN IP로 connect → Subscribe·TTS·IR 송신.

공유기에서 ESP32 MAC에 **DHCP 예약(고정 IP)** 을 걸어 두면 백엔드 설정이 안정적입니다.

---

## 3. 연결 수명 주기 (Lifecycle)

```mermaid
sequenceDiagram
    participant ESP as ESP32 (:41737)
    participant BE as 백엔드

    ESP->>ESP: WiFi 연결
    ESP->>ESP: TCP listen :41737
    BE->>ESP: TCP connect
    loop 주기적 (예: 5초)
        BE->>ESP: Heartbeat (ControlHeader, body 없음)
        ESP->>BE: Heartbeat (선택)
    end
    BE->>ESP: Subscribe (MicComp)
    ESP->>BE: Ack (status=0)
    loop 마이크 스트리밍
        ESP->>BE: DataHeader(MicComp) + Opus 프레임
    end
    BE->>ESP: IrTransmit + raw 타이밍
    ESP->>ESP: IR LED 송신
    BE->>ESP: Unsubscribe (MicComp)
    ESP->>BE: Ack
    Note over ESP: 마이크 스트리밍 중지
    BE->>ESP: TCP close (또는 끊김)
    ESP->>ESP: accept() 대기 (다음 클라이언트)
```

### 3.1 ESP32 메인 루프에서 할 일

```
부팅
  │
  ├─ GPIO / I2S / IR 초기화
  ├─ WiFi.begin(SSID, PASS)
  ├─ TCP server bind(0.0.0.0, 41737) + listen
  │
  └─ while (true)
        ├─ client = accept()          // 백엔드 접속 대기
        ├─ 구독 상태 초기화 (선택)
        └─ while (client 연결 유지)
              ├─ client에서 읽을 데이터 → 패킷 파싱 → 명령 큐
              ├─ Subscribe, IrTransmit, SpkComp 처리
              ├─ 마이크/IR/센서 패킷 → client로 send
              └─ (선택) Heartbeat 응답
        └─ client disconnect → 다시 accept()
```

연결이 끊기면 ESP32는 **다시 accept()만 하면 됩니다**. 재접속은 **백엔드**가 담당합니다 (지수 백오프: 1s → 2s → 4s … 최대 30s).

---

## 4. ESP32 내부 파이프라인 (권장 구조)

FreeRTOS 태스크로 나누면 블로킹이 줄어듭니다.

```mermaid
flowchart TB
    subgraph Tasks["FreeRTOS 태스크"]
        T_NET["net_task<br/>accept / read / write"]
        T_CMD["cmd_task<br/>Subscribe 처리"]
        T_MIC["mic_task<br/>I2S 캡처"]
        T_ENC["encode_task<br/>Opus (선택)"]
        T_IR["ir_task<br/>IR 수신/송신"]
        T_SPK["spk_task<br/>재생 (선택)"]
        T_SENS["sensor_task<br/>센서 폴링"]
    end

    Q_RX["Queue: raw TCP bytes"]
    Q_CMD["Queue: parsed commands"]
    Q_MIC["Queue: PCM frames"]
    Q_TX["Queue: packets to send"]

    T_NET --> Q_RX --> T_CMD
    T_CMD -->|"Subscribe ON"| T_MIC
    T_MIC --> Q_MIC --> T_ENC --> Q_TX
    T_IR --> Q_TX
    T_SENS --> Q_TX
    Q_TX --> T_NET
    T_NET -->|"SpkComp / IrTransmit"| T_SPK
    T_NET --> T_IR
```

### 4.1 태스크별 역할

| 태스크 | 입력 | 출력 | 주기 |
| --- | --- | --- | --- |
| net_task | TCP client socket (accept 결과) | 파싱된 패킷 / 송신 큐 | 이벤트驱动 |
| cmd_task | ControlHeader 패킷 | 구독 플래그 변경, Ack 송신 | 이벤트 |
| mic_task | I2S DMA | 20ms PCM 버퍼 | 20ms |
| encode_task | PCM | Opus 프레임 | 20ms |
| ir_task | IR 수신 핀 | IrReceive 패킷 / LED 송신 | 이벤트 |
| spk_task | SpkComp 패킷 | I2S DAC 출력 | 20ms |
| sensor_task | I2C 센서 | SensorBody 패킷 | intervalMs |

### 4.2 공유 상태 (간단한 플래그)

```cpp
struct SubscriptionState {
    bool mic_pcm;
    bool mic_comp;
    bool ambient_light;
    bool temperature;
    bool humidity;
    uint16_t sensor_interval_ms;
};
```

`Subscribe` 수신 시 해당 `targetType`을 true로, `Unsubscribe` 시 false로 바꿉니다.

---

## 5. TCP 수신 파이프라인 (백엔드 → ESP32)

백엔드(클라이언트)에서 오는 바이트를 패킷으로 만드는 과정입니다.

```mermaid
flowchart LR
    A["TCP recv<br/>바이트 스트림"] --> B["링 버퍼에 append"]
    B --> C{"16바이트 이상?"}
    C -->|No| A
    C -->|Yes| D["헤더 파싱<br/>magic == WSP1?"]
    D -->|실패| E["연결 종료 또는 resync"]
    D -->|성공| F{"header + payloadSize<br/>전부 모였나?"}
    F -->|No| A
    F -->|Yes| G["완성 패킷을 cmd_task에 전달"]
    G --> H["링 버퍼에서 패킷 제거"]
    H --> A
```

### 5.1 파싱 의사코드

```cpp
// ring buffer에 data가 쌓여 있다고 가정
while (ring.size() >= 16) {
    auto hdr = peek_header(ring);  // ControlHeader or DataHeader (둘 다 16B)
    if (hdr.magic != 0x57535031) { disconnect(); return; }
    if (hdr.version != 1) { send_error(...); continue; }

    size_t total = 16 + hdr.payloadSize;
    if (hdr.payloadSize > 4096) { disconnect(); return; }
    if (ring.size() < total) break;  // 더 recv 대기

    Packet pkt = ring.pop(total);
    dispatch(pkt);
}
```

### 5.2 dispatch: 타입별 처리

| type | ESP32 동작 |
| --- | --- |
| Subscribe | 구독 플래그 켜기 → Ack 송신 |
| Unsubscribe | 구독 플래그 끄기 → Ack 송신 |
| Heartbeat | 무시하거나 동일하게 응답 |
| SpkPCM / SpkComp | spk_task 큐에 넣기 |
| IrTransmit | ir_task에 raw 배열 전달 |
| Error | 로그 출력 |

---

## 6. TCP 송신 파이프라인 (ESP32 → 백엔드)

```mermaid
flowchart LR
    A["mic / ir / sensor<br/>데이터 준비"] --> B["Body struct 채우기"]
    B --> C["DataHeader 작성<br/>sequence++"]
    C --> D["16 + payload 를<br/>하나의 버퍼에"]
    D --> E["TCP send 한 번"]
```

### 6.1 패킷 조립 예 (MicComp)

```
[ DataHeader 16B ]
[ AudioCompBody 9B ]  ← codec, sampleRate, encodedSize ...
[ encodedData N B ]
```

`payloadSize` = 9 + N (타임스탬프 안 쓸 때).

`sequence`는 **타입마다 따로** 0부터 증가시킵니다 (MicComp용, IrReceive용 각각).

### 6.2 송신 시 주의

- send 버퍼 하나에 헤더+바디를 **합쳐서** 한 번에 보냅니다.
- WiFi가 느릴 때 큐가 차면 **오래된 오디오 프레임을 버리는** 쪽이 실시간에 유리합니다 (최신 2~3프레임만 유지).

---

## 7. 기능별 파이프라인

### 7.1 마이크 (INMP441 → 백엔드)

하드웨어: INMP441은 **I2S**로 연결합니다.

```mermaid
flowchart LR
    MIC["INMP441"] --> I2S["I2S RX DMA<br/>16kHz mono 16bit"]
    I2S --> BUF["20ms PCM 버퍼<br/>320 samples = 640 bytes"]
    BUF --> CHK{"mic_comp<br/>구독 중?"}
    CHK -->|No| DROP["버림"]
    CHK -->|Yes| ENC["Opus encode"]
    ENC --> PKT["MicComp 패킷"]
    PKT --> TCP["TCP send"]
```

권장 값 (백엔드와 맞출 것):

| 항목 | 값 |
| --- | --- |
| sampleRate | 16000 |
| channels | 1 |
| bitsPerSample | 16 |
| frame | 320 samples / 20 ms |
| codec | Opus |

**MicPCM** 단계에서는 Opus 없이 PCM을 그대로 `AudioPCMBody` 뒤에 붙여내면 디버깅이 쉽습니다.

#### I2S 핀 (DevKitC v4 예시 — 팀에서 한 번 고정)

| 신호 | ESP32 핀 (예시) |
| --- | --- |
| BCK | GPIO 26 |
| WS (LRCK) | GPIO 25 |
| DATA IN | GPIO 33 |

실제 핀은 배선에 맞게 문서화하고 바꾸지 않는 것이 좋습니다.

---

### 7.2 스피커 (백엔드 → ESP32 → 스피커)

스피커 모듈이 아직 없어도 **파이프라인만** 먼저 만들 수 있습니다 (I2S TX 또는 DAC).

```mermaid
flowchart LR
    TCP["TCP recv<br/>SpkComp"] --> DEC["Opus decode"]
    DEC --> PCM["PCM 20ms"]
    PCM --> I2S["I2S TX / DAC"]
    I2S --> SPK["스피커"]
```

백엔드가 보낸 `SpkComp`는 **Subscribe 없이** 바로 올 수 있습니다 (일회성 재생). 연속 스트리밍이면 백엔드에서 프레임을 꾸준히 보냅니다.

`HeaderFlag_KeyFrameBit`가 켜진 프레임이 오면 Opus 디코더를 리셋합니다.

---

### 7.3 IR 수신 (리모컨 → 백엔드)

라이브러리: **IRremoteESP8266** (ESP32에서도 사용 가능).

```mermaid
flowchart LR
    BTN["리모컨"] --> IRX["IR 수신 모듈"]
    IRX --> LIB["decode_raw()"]
    LIB --> RAW["uint16_t[] μs 타이밍"]
    RAW --> BODY["IrReceiveBody"]
    BODY --> PKT["DataHeader + body"]
    PKT --> TCP["TCP send"]
```

흐름:

1. IR 핀에서 신호 감지
2. 라이브러리가 mark/space 길이 배열 생성
3. tick이 아니라 **마이크로초(μs)** 로 변환
4. `IrReceiveBody.length` + `rawData[]` 를 패킷에 실어 백엔드로 전송

백엔드는 이 raw 배열로 에어컨/TV 프로토콜을 해석하거나 그대로 저장합니다.

---

### 7.4 IR 송신 (백엔드 → ESP32 → 가전)

```mermaid
flowchart LR
    TCP["IrTransmit 패킷"] --> PARSE["carrierHz, repeat, rawData"]
    PARSE --> SEND["IRsend::sendRaw()"]
    SEND --> LED["IR LED"]
    LED --> TV["TV / 에어컨"]
```

`IrTransmitBody` 뒤의 `rawData`는 수신과 동일하게 **μs, mark부터 시작, mark/space 교대**입니다.

---

### 7.5 센서 (조도 / 온도 / 습도)

센서가 없어도 **가짜 값**으로 파이프라인을 검증할 수 있습니다.

```mermaid
flowchart LR
    SUB["Subscribe<br/>AmbientLight, intervalMs=1000"] --> ACK["Ack"]
    ACK --> LOOP["1초마다"]
    LOOP --> READ["센서 읽기"]
    READ --> BODY["SensorBody<br/>unit, value, quality"]
    BODY --> TCP["TCP send"]
```

`SubscribeOptionFlag_OnChangeOnlyBits`가 켜져 있으면 값이 변할 때만 보냅니다.

---

## 8. Subscribe / Ack 흐름 (가장 자주 쓰는 제어)

```mermaid
sequenceDiagram
    participant BE as 백엔드
    participant CMD as cmd_task
    participant MIC as mic_task

    BE->>CMD: ControlHeader Subscribe<br/>targetType=MicComp
    CMD->>CMD: subscription.mic_comp = true
    CMD->>BE: ControlHeader Ack<br/>requestId 동일, status=0
    MIC->>MIC: mic_comp == true 확인
    loop every 20ms
        MIC->>BE: DataHeader MicComp + Opus
    end
    BE->>CMD: Unsubscribe MicComp
    CMD->>CMD: subscription.mic_comp = false
    CMD->>BE: Ack
```

### SubscribeBody 해석

| 필드 | 마이크 예 | 센서 예 |
| --- | --- | --- |
| targetType | `0x0102` (MicComp) | `0x0301` (AmbientLight) |
| intervalMs | `0` (최대 속도) | `1000` (1초마다) |
| options | `Compressed` 비트 | `OnChangeOnly` 선택 |

---

## 9. 공유기·네트워크 (ESP32 펌웨어)

| 항목 | 내용 |
| --- | --- |
| WiFi | 공유기 SSID/비밀번호로 STA 모드 접속 |
| ESP32 IP  | DHCP (공유기에서 MAC 기준 **고정 IP 예약** 권장) |
| listen 주소 | `0.0.0.0:41737` |
| 동시 접속 | v1은 **클라이언트 1개**만 accept (백엔드만 연결)  |

부팅 후 시리얼 로그에 `WiFi connected, IP=192.168.x.x, listening on 41737` 형태로 출력해 두면 현장 디버깅에 유리합니다.

---

## 10. 백엔드 개발자가 알아둘 것

| 항목 | 내용 |
| --- | --- |
| 연결 대상 | ESP32 LAN IP (예: `192.168.0.50`) |
| 포트 | **41737** TCP (`wsp::kTcpPort`) |
| 역할 | **클라이언트** — `connect(esp32_ip, 41737)` |
| 엔디안 | 전부 little-endian |
| Magic | 수신 시 반드시 `WSP1` 검사 |
| 최대 payload | 4096 bytes |
| 재접속 | 끊기면 백엔드가 재 connect |

테스트: `nc esp32_ip 41737` 로 TCP만 열리는지 확인 후, Subscribe 패킷을 보냅니다.

백엔드 API 연동은 [agent-tool-api.md](./agent-tool-api.md)의 **백엔드 → WaveStation** 절을 참고합니다.

---

## 11. ESP32 프로젝트 구성 (Arduino / ESP-IDF)

### 11.1 필요 라이브러리 (예시)

| 기능 | 라이브러리 |
| --- | --- |
| WiFi / TCP | ESP-IDF `esp_wifi`, `lwip` 또는 Arduino `WiFi.h` |
| I2S 마이크 | ESP-IDF `driver/i2s` |
| IR | IRremoteESP8266 |
| Opus | esp-opus 또는 libopus (나중 단계) |

### 11.2 메모리

- TCP 수신 링 버퍼: 8 KB 이상 권장
- Opus 프레임 버퍼: 1~2 KB
- IR raw: 최대 512개 `uint16_t`; 초과하면 overflow 플래그를 설정

---

## 12. 자주 하는 실수

| 증상 | 원인 | 해결 |
| --- | --- | --- |
| PC가 패킷을 못 읽음 | TCP에 헤더만 보내고 body를 따로 send | **한 번의 send**에 합치기 |
| magic 불일치 | 엔디안 착각, 잘못된 offset | `uint32_t`를 그대로 memcpy, `#pragma pack(1)` |
| 마이크가 안 옴 | Subscribe 전에 송신 | Subscribe + Ack 이후에만 Mic 송신 |
| 소리 깨짐 | sampleRate 불일치 | 16000 / mono / 16bit 통일 |
| IR 재생 실패 | μs가 아닌 tick 그대로 전송 | μs로 변환 후 전송 |
| 연결 자주 끊김 | Heartbeat 없음 | 백엔드가 5~10초마다 Heartbeat 송신 |
| payloadSize 틀림 | 고정 body만 넣고 pcm/opus 길이 누락 | `payloadSize = body + 가변데이터` |

---

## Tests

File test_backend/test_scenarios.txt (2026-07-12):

WaveStation quick test scenarios

Replace <ESP32_IP> with the LAN IP printed in the serial monitor.
Run these commands from the test_backend directory.

1. Heartbeat
python wave_station_test_backend.py <ESP32_IP>

2. MicPCM stream and raw recording
python wave_station_test_backend.py <ESP32_IP> --subscribe micpcm --pcm-out mic.raw --heartbeat-interval 0
ffplay -f s16le -ar 16000 -ac 1 mic.raw

3. MicComp Opus frame recording
python wave_station_test_backend.py <ESP32_IP> --subscribe miccomp --opus-out-dir opus_frames --heartbeat-interval 0

4. IR receive
python wave_station_test_backend.py <ESP32_IP> --subscribe ir --ir-jsonl ir_raw.jsonl --heartbeat-interval 0

5. IR transmit
python wave_station_test_backend.py <ESP32_IP> --send-ir-raw "9000,4500,560,560,560,1690" --carrier-hz 38000 --repeat 0 --heartbeat-interval 0

6. Environment sensors
python wave_station_test_backend.py <ESP32_IP> --subscribe ambient temperature humidity --heartbeat-interval 0

7. Speaker tone
python wave_station_test_backend.py <ESP32_IP> --send-spkpcm-tone --tone-freq 880 --tone-duration 2 --tone-amp 0.15 --heartbeat-interval 0

8. Speaker WAV
python wave_station_test_backend.py <ESP32_IP> --send-spkpcm-wav mic.wav --heartbeat-interval 0

9. Speaker Opus frames
python wave_station_test_backend.py <ESP32_IP> --send-spkcomp-dir opus_frames --heartbeat-interval 0

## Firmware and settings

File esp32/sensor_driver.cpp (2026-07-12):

#include "sensor_driver.h"

#include <Wire.h>
#include <DHT.h>
#include <BH1750.h>

static DHT* g_dht = nullptr;
static BH1750 g_lightMeter;
static bool g_dhtReady = false;
static bool g_lightReady = false;
static const char* g_sensorStatus = "not initialized";

bool sensorsBegin(uint8_t dhtPin, int sdaPin, int sclPin) {
  Serial.printf("[sensor] begin: DHT22 DATA=%u, BH1750 SDA=%d SCL=%d\n", dhtPin, sdaPin, sclPin);

  static DHT dhtStatic(dhtPin, DHT22);
  g_dht = &dhtStatic;
  g_dht->begin();
  g_dhtReady = true;

  Wire.begin(sdaPin, sclPin);
  g_lightReady = g_lightMeter.begin(BH1750::CONTINUOUS_HIGH_RES_MODE, 0x23, &Wire);

  if (g_dhtReady && g_lightReady) {
    g_sensorStatus = "DHT22 and BH1750 ready";
  } else if (g_dhtReady) {
    g_sensorStatus = "DHT22 ready, BH1750 not detected";
  } else if (g_lightReady) {
    g_sensorStatus = "BH1750 ready, DHT22 not ready";
  } else {
    g_sensorStatus = "sensors not ready";
  }

  Serial.printf("[sensor] %s\n", g_sensorStatus);
  return g_dhtReady || g_lightReady;
}

bool dhtReady() {
  return g_dhtReady && g_dht != nullptr;
}

bool lightReady() {
  return g_lightReady;
}

const char* sensorStatus() {
  return g_sensorStatus;
}

SensorReadings sensorsReadAll() {
  SensorReadings out;

  if (g_lightReady) {
    const float lux = g_lightMeter.readLightLevel();
    if (!isnan(lux) && lux >= 0.0f) {
      out.hasLux = true;
      out.lux = lux;
    }
  }

  if (dhtReady()) {
    const float t = g_dht->readTemperature();
    const float h = g_dht->readHumidity();

    if (!isnan(t)) {
      out.hasTemperature = true;
      out.temperatureC = t;
    }
    if (!isnan(h)) {
      out.hasHumidity = true;
      out.humidityPct = h;
    }
  }

  return out;
}

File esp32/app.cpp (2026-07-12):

#include <Arduino.h>
#include <WiFi.h>
#include <esp_system.h>
#include <math.h>

// Opus 인코딩/디코딩과 오디오 버퍼가 사용하는 스택을 고려해
// Arduino Core가 생성하는 loopTask의 스택 크기를 확장합니다.
size_t getArduinoLoopTaskStackSize(void) {
  return 49152;
}

#include "wave_station.h"
#include "wsp_packet.h"
#include "i2s_mic.h"
#include "opus_codec.h"
#include "ir_driver.h"
#include "sensor_driver.h"
#include "speaker_driver.h"

// -----------------------------------------------------------------------------
// Wi-Fi 접속 정보
// -----------------------------------------------------------------------------
const char* WIFI_SSID = "PUT_YOUR_WIFI_SSID";
const char* WIFI_PASS = "PUT_YOUR_WIFI_PASSWORD";

// -----------------------------------------------------------------------------
// 하드웨어 핀
// -----------------------------------------------------------------------------
constexpr int I2S_MIC_BCLK_PIN = 14;  // INMP441 SCK
constexpr int I2S_MIC_LRCK_PIN = 15;  // INMP441 WS
constexpr int I2S_MIC_DATA_PIN = 32;  // INMP441 SD

constexpr uint16_t IR_RECV_PIN = 27;  // IR 수신 OUT
constexpr uint16_t IR_SEND_PIN = 26;  // IR 송신 S

constexpr uint8_t DHT22_DATA_PIN = 25;

constexpr int BH1750_SDA_PIN = 21;
constexpr int BH1750_SCL_PIN = 22;

constexpr int SPK_BCLK_PIN = 18;  // MAX98357 BCLK
constexpr int SPK_LRCK_PIN = 19;  // MAX98357 LRC
constexpr int SPK_DIN_PIN  = 23;  // MAX98357 DIN

// -----------------------------------------------------------------------------
// 네트워크 및 세션 상태
// -----------------------------------------------------------------------------
WiFiServer server(wsp::kTcpPort);
WiFiClient client;

SubscriptionState sub;

uint32_t micPcmSeq = 0;
uint32_t micCompSeq = 0;
uint32_t irReceiveSeq = 0;
uint32_t ambientSeq = 0;
uint32_t temperatureSeq = 0;
uint32_t humiditySeq = 0;

// TCP는 스트림이므로 수신 데이터를 누적한 뒤 완성된 WSP 패킷 단위로 파싱합니다.
constexpr size_t RX_BUFFER_SIZE = 8192;
uint8_t rxBuffer[RX_BUFFER_SIZE];
size_t rxSize = 0;

// MicPCM 한 프레임: 16 kHz × 20 ms = 320 samples = 640 bytes (mono, 16-bit).
constexpr uint16_t MIC_FRAME_SAMPLES = 320;
int16_t micFrame[MIC_FRAME_SAMPLES];

static int16_t spkDecodePcm[OPUS_MAX_DECODED_SAMPLES];

// 센서 전송 주기 및 변화 감지 상태
uint32_t lastAmbientMs = 0;
uint32_t lastTempMs = 0;
uint32_t lastHumMs = 0;
bool haveLastAmbient = false;
bool haveLastTemp = false;
bool haveLastHum = false;
float lastAmbientValue = 0.0f;
float lastTempValue = 0.0f;
float lastHumValue = 0.0f;

// -----------------------------------------------------------------------------
// 공통 유틸리티
// -----------------------------------------------------------------------------
static uint16_t normalizedSensorInterval(uint16_t intervalMs, uint16_t minMs, uint16_t defaultMs) {
  uint16_t value = intervalMs == 0 ? defaultMs : intervalMs;
  if (value < minMs) value = minMs;
  return value;
}

static bool changedEnough(float prev, float now, float threshold) {
  return fabsf(now - prev) >= threshold;
}

void resetSessionState() {
  sub = SubscriptionState{};
  rxSize = 0;
  micPcmSeq = 0;
  micCompSeq = 0;
  irReceiveSeq = 0;
  ambientSeq = 0;
  temperatureSeq = 0;
  humiditySeq = 0;
  lastAmbientMs = 0;
  lastTempMs = 0;
  lastHumMs = 0;
  haveLastAmbient = false;
  haveLastTemp = false;
  haveLastHum = false;
}

void disconnectClient(const char* reason) {
  Serial.print("[net] disconnect: ");
  Serial.println(reason);

  if (client) {
    client.stop();
  }

  resetSessionState();
}

void printIpInfo() {
  Serial.print("WiFi connected, IP=");
  Serial.print(WiFi.localIP());
  Serial.print(", listening on ");
  Serial.println(wsp::kTcpPort);
}

void connectWifi() {
  Serial.print("[wifi] connecting to ");
  Serial.println(WIFI_SSID);

  WiFi.mode(WIFI_STA);
  WiFi.begin(WIFI_SSID, WIFI_PASS);

  while (WiFi.status() != WL_CONNECTED) {
    delay(500);
    Serial.print('.');
  }

  Serial.println();
  printIpInfo();
}

// -----------------------------------------------------------------------------
// WSP 제어 및 데이터 패킷 처리
// -----------------------------------------------------------------------------
void handleSubscribe(uint32_t requestId, const uint8_t* payload, uint32_t payloadSize) {
  if (payloadSize != sizeof(wsp::SubscribeBody)) {
    wspSendError(client, requestId, wsp::ErrorInvalidPayload, "invalid SubscribeBody size");
    return;
  }

  wsp::SubscribeBody body;
  memcpy(&body, payload, sizeof(body));

  const uint16_t micPcmType = static_cast<uint16_t>(wsp::Type::MicPCM);
  const uint16_t micCompType = static_cast<uint16_t>(wsp::Type::MicComp);
  const uint16_t irReceiveType = static_cast<uint16_t>(wsp::Type::IrReceive);
  const uint16_t ambientType = static_cast<uint16_t>(wsp::Type::AmbientLight);
  const uint16_t temperatureType = static_cast<uint16_t>(wsp::Type::Temperature);
  const uint16_t humidityType = static_cast<uint16_t>(wsp::Type::Humidity);

  const bool onChangeOnly = (body.options & wsp::SubscribeOptionFlag_OnChangeOnlyBits) != 0;

  Serial.printf("[rx] Subscribe target=0x%04X intervalMs=%u options=0x%08lX requestId=%lu\n",
                body.targetType,
                body.intervalMs,
                static_cast<unsigned long>(body.options),
                static_cast<unsigned long>(requestId));

  if (body.targetType == micPcmType) {
    sub.mic_pcm = true;
    wspSendAck(client, requestId, 0);
    Serial.println("[sub] MicPCM ON");
    return;
  }

  if (body.targetType == micCompType) {
    if (!opusEncoderReady()) {
      Serial.printf("[sub] MicComp rejected: %s\n", opusStatus());
      wspSendError(client, requestId, wsp::ErrorUnsupported, "MicComp Opus encoder not ready");
      return;
    }
    sub.mic_comp = true;
    wspSendAck(client, requestId, 0);
    Serial.println("[sub] MicComp ON");
    return;
  }

  if (body.targetType == irReceiveType) {
    irClearReceive();  // 구독 이전에 남아 있던 수신 결과를 폐기합니다.
    sub.ir_receive = true;
    wspSendAck(client, requestId, 0);
    Serial.println("[sub] IrReceive ON");
    return;
  }

  if (body.targetType == ambientType) {
    if (!lightReady()) {
      wspSendError(client, requestId, wsp::ErrorUnsupported, "BH1750 ambient light sensor not ready");
      return;
    }
    sub.ambient_light = true;
    sub.ambient_interval_ms = normalizedSensorInterval(body.intervalMs, 200, 1000);
    sub.ambient_on_change_only = onChangeOnly;
    lastAmbientMs = 0;
    haveLastAmbient = false;
    wspSendAck(client, requestId, 0);
    Serial.printf("[sub] AmbientLight ON interval=%u onChange=%u\n", sub.ambient_interval_ms, onChangeOnly ? 1 : 0);
    return;
  }
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
